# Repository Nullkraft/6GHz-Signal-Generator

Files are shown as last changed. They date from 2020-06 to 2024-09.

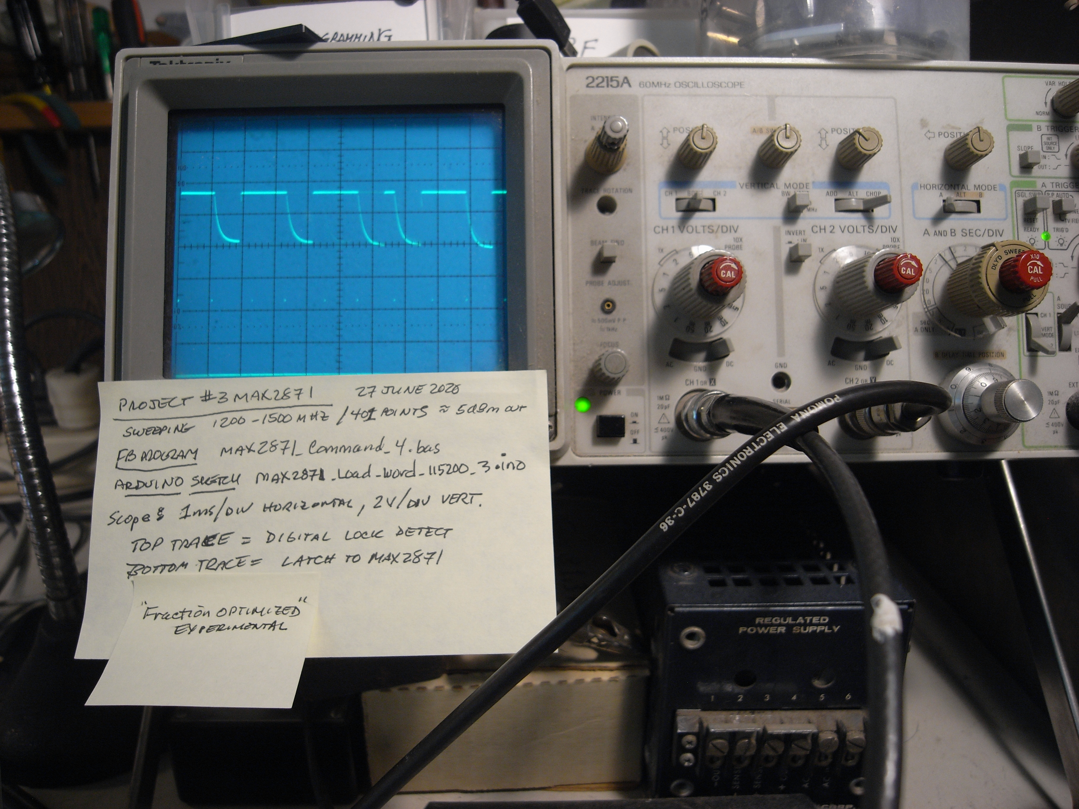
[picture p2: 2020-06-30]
Test_Data_27June2020/Timing_MAX2871_Sweep_1200-1500MHz_401pts_1ms_FracOpt.jpg

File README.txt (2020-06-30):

README for PROJECT#3 Synthesizer 6 April 2020- WN2A

A synthesizer compatible with Arduino UNO R3 Microcontroller and others.

1) Schematics: are Unembedded: wn2a-SigGen-page1B_Unembed.sch
                   Enbedded: wn2a-SigGen-page1B_Embed.sch
    
   A combination of Mark Stanley/Mike Masterson gEDA .schematics 
    
2) BOM is PROJECT#3_Synthesizer.ods

3) MAX2871 is drawn on schematic as it looks from its top-view.
    The reason is so to better visualize the optimal positions of bypass capacitors,
    for the purpose of maximizing output power especially above 3000 MHz. 

3) Design is intended to meet preliminary specifications:
   Frequency Range :23.5-6000 MHz. Step size 1KHz at min setting (TBD)
   RF Power approx -5 to +4dBm
   Harmonic Output ~ -30dBc
   Dual outputs, with divider options per MAX2871
   Powered by either by Arduino UNO R3 OR External +7 ~ +13V (Schottky Diode OR'd)
   Programmed with same interface and sketches as PROJECT#1 LO#2 ,
    (For which the MAX2871 will be LO#2 and LO#3)
   XTAL Reference 60.000 MHz for low phase noise.
   Individual AZ1117 low-noise regulators for Digital,RF and VCO
   Broadband output network.
   LOCK DET SMD LED indicator 
   Compatible with Arduino UNO R3.

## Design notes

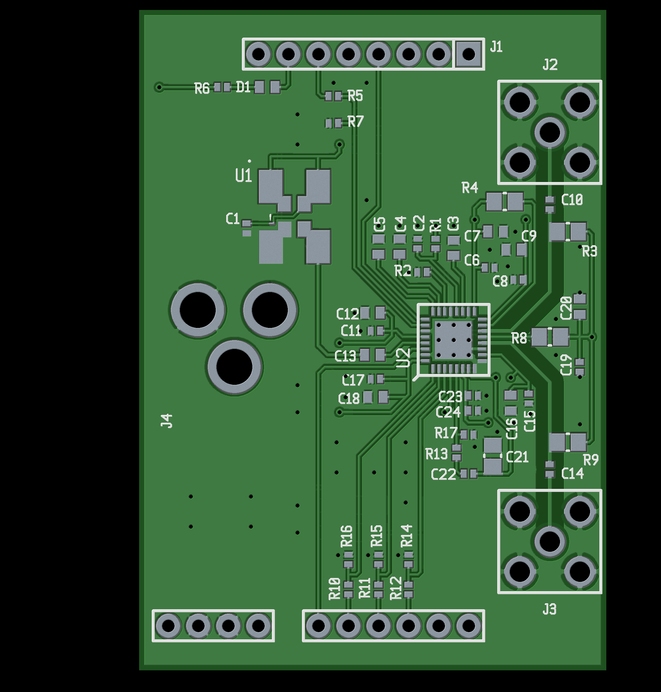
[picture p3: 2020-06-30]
Schematics/wn2a-SigGen_TOP.png

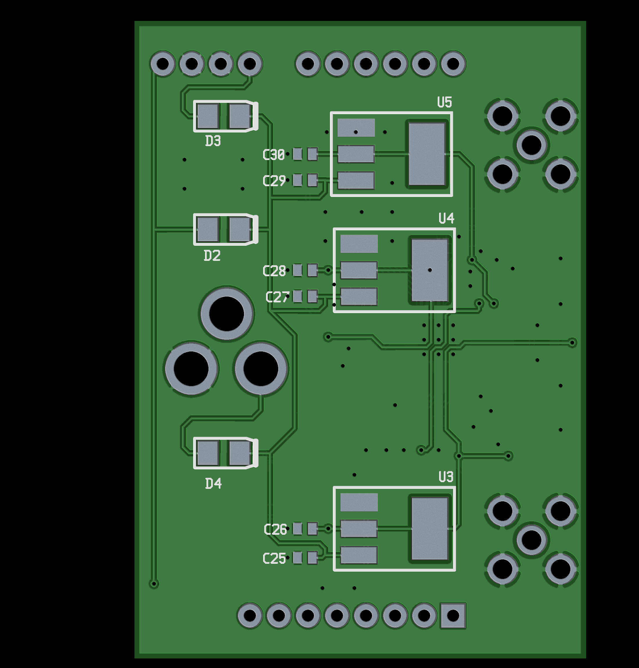
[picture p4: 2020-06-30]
Schematics/wn2a-SigGen_BOT.png

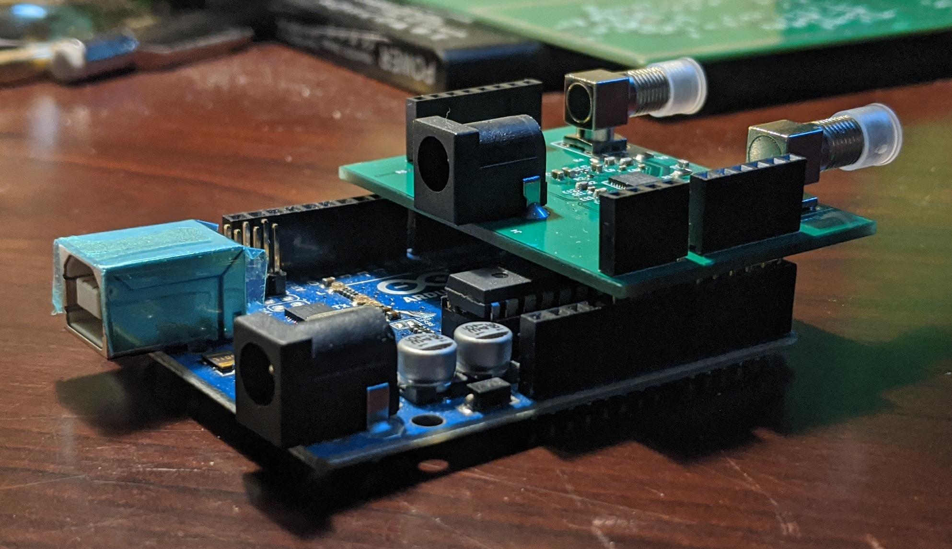
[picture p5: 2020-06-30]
Signal Generator mounting position.jpg

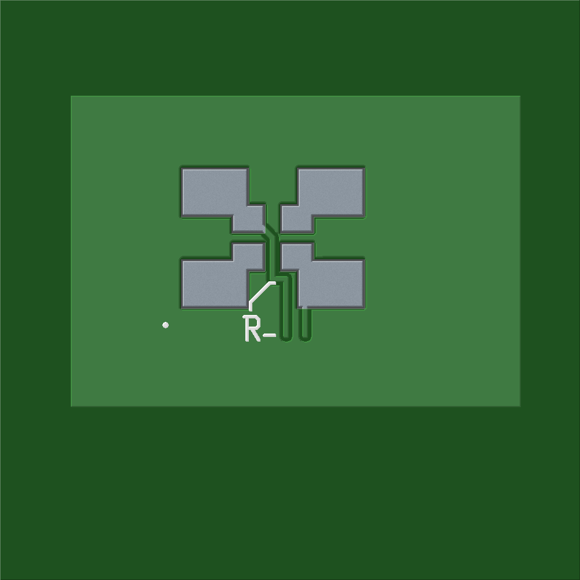
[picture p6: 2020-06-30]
ASx_Series_Oscillator.fp.png

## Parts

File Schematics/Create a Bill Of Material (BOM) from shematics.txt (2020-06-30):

Create a Bill Of Material (BOM) from shematics

Open the terminal and enter the following commands :

   - cd /Document_of_your_project
   - touch attribs : create a file that will contain the attributes you want to include in the BOM
   - touch bom.txt : Create the txt file
   - cat bom.txt : see a preview of bom.txt
   - cat attribs : see which attribs you have added
   - vi attribs : then press i to go in insertion mode
   - and write the 'options' you want to add at your build of material. (value, footprint) Refdes is automatically added.
   - when you finish presse enter, ESC and write :wq use to get out of vi attribs

   - gnetlist -g bom2 -o bom.txt wn2a-SigGen-page1.sch

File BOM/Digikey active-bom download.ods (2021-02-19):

Manufacturer Part Number | Manufacturer | Reference Designator | Digi-Key Part Number | Packaging | Part Status | Quantity | Unit Price | Extended Price | Quantity Available | Description
885012205031 | Würth Elektronik | C1 | 732-7526-1-ND | Cut Tape (CT) | Active | 10 | 0.01 | $0.10 | 71070 | CAP CER 10000PF 16V X7R 0402
885012005057 | Würth Elektronik | C10, C14 | 732-7471-1-ND | Cut Tape (CT) | Active | 10 | 0.015 | $0.15 | 32510 | CAP CER 22PF 50V C0G/NP0 0402
885012006029 | Würth Elektronik | C13 | 732-7771-1-ND | Cut Tape (CT) | Active | 1 | 0.1 | $0.10 | 7147 | CAP CER 1000PF 16V C0G/NP0 0603
GRM2195C1H123JA01D | Murata Electronics | C21 | 490-3320-1-ND | Cut Tape (CT) | Active | 1 | 0.48 | $0.48 | 29880 | CAP CER 0.012UF 50V C0G/NP0 0805
885012205037 | Würth Elektronik | C22, C24 | 732-7532-1-ND | Cut Tape (CT) | Active | 10 | 0.02 | $0.20 | 140294 | CAP CER 0.1UF 16V X7R 0402
885012206052 | Würth Elektronik | C25, C26, C27, C28, C29, C3, C30, C4, C5 | 732-7971-1-ND | Cut Tape (CT) | Active | 10 | 0.144 | $1.44 | 4469 | CAP CER 1UF 16V X7R 0603
1N5819HW-7-F | Diodes Incorporated | D2, D3, D4 | 1N5819HW-FDICT-ND | Cut Tape (CT) | Active | 3 | 0.4 | $1.20 | 493583 | DIODE SCHOTTKY 40V 1A SOD123
85 | Adafruit Industries LLC | J1 | 1528-1074-ND | Bulk | Active | 1 | 1.95 | $1.95 | 2293 | STACKING HEADER ARDUINO SHIELD
CRCW04021K00FKEDC | Vishay Dale | R10, R11, R12, R5 | 541-3961-1-ND | Cut Tape (CT) | Active | 10 | 0.032 | $0.32 | 443436 | RES SMD 1K OHM 1% 1/16W 0402
CRCW040230R1FKED | Vishay Dale | R13 | 541-30.1LCT-ND | Cut Tape (CT) | Active | 1 | 0.1 | $0.10 | 22808 | RES SMD 30.1 OHM 1% 1/16W 0402
CRCW04021K50FKEDC | Vishay Dale | R14, R15, R16, R7 | 541-4782-1-ND | Cut Tape (CT) | Active | 10 | 0.032 | $0.32 | 43118 | RES 1.5K OHM 1% 1/16W 0402

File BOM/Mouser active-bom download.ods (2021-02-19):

Mouser # | Mfr. # | Manufacturer | Customer # | Description | RoHS | Lifecycle | Order Qty. | Price (USD) | Ext.: (USD)
700-MAX2871ETJ+ | MAX2871ETJ+ | Maxim Integrated |  | Phase Locked Loops - PLL 23.5MHz to 6000MHz Fractional/IntegerN Synthesizer/VCO | RoHS Compliant |  | 1 | $11.64 | $11.64
71-CRCW04025K10FKEDC | CRCW04025K10FKEDC | Vishay |  | Thick Film Resistors - SMD 1/16watt 5.1Kohms 1% Commercial Use | RoHS Compliant By Exemption |  | 1 | $0.10 | $0.10
71-CRCW040290R9FKEDC | CRCW040290R9FKEDC | Vishay |  | Thick Film Resistors - SMD 1/16watt 90.9ohms 1% Commercial Use | RoHS Compliant By Exemption |  | 1 | $0.10 | $0.10
71-CRCW0402240RFKEDC | CRCW0402240RFKEDC | Vishay |  | Thick Film Resistors - SMD 1/16watt 240ohms 1% Commercial Use | RoHS Compliant By Exemption |  | 1 | $0.10 | $0.10
81-GCM1555C1H821JA6D | GCM1555C1H821JA16D | Murata |  | Multilayer Ceramic Capacitors MLCC - SMD/SMT 0402 820pF 50volts C0G 5% | RoHS Compliant |  | 1 | $0.10 | $0.10
81-GRM1885C1H103JA1J | GRM1885C1H103JA01J | Murata |  | Multilayer Ceramic Capacitors MLCC - SMD/SMT .01UF 50V 5% 0603 | RoHS Compliant |  | 10 | $0.148 | $1.48
815-ASE60.000MHZLCT | ASE-60.000MHZ-LC-T | ABRACON |  | Standard Clock Oscillators XTAL OSC XO 60.0000MHZ CMOS SMD | RoHS Compliant | New Product | 1 | $1.53 | $1.53
621-AZ1117EH-3.3TRG1 | AZ1117EH-3.3TRG1 | Diodes Incorporated |  | LDO Voltage Regulators LDO BJT HiCurr | RoHS Compliant |  | 10 | $0.281 | $2.81
992-CON-SOCJ-2155 | CON-SOCJ-2155 | Gravitech |  | DC Power Connectors Power Jack/Connector 2.1mm x 5.5mm | RoHS Compliant |  | 1 | $1.00 | $1.00
710-885012205020 | 885012205020 | Wurth Elektronik |  | Multilayer Ceramic Capacitors MLCC - SMD/SMT WCAP-CSGP 150pF 0402 10% 16V MLCC | RoHS Compliant |  | 10 | $0.013 | $0.13
71-CRCW080551R0FKEA | CRCW080551R0FKEA | Vishay |  | Thick Film Resistors - SMD 1/8watt 51ohms 1% | RoHS Compliant By Exemption |  | 4 | $0.10 | $0.40
571-619540-1 | 619540-1 | TE Connectivity |  | RF Connectors / Coaxial Connectors SMA RIGHT ANGLE PCB JACK | RoHS Compliant |  | 2 | $3.40 | $6.80

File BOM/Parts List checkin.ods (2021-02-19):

Source | Digi-Key Part Number | Manufacturer Part Number | Reference Designator | Description
Digikey | 732-7526-1-ND | 885012205031 | C1 | CAP CER 10000PF 16V X7R 0402
Digikey | 732-7471-1-ND | 885012005057 | C10, C14 | CAP CER 22PF 50V C0G/NP0 0402
Digikey | 732-7771-1-ND | 885012006029 | C13 | CAP CER 1000PF 16V C0G/NP0 0603
Digikey | 490-3320-1-ND | GRM2195C1H123JA01D | C21 | CAP CER 0.012UF 50V C0G/NP0 0805
Digikey | 732-7532-1-ND | 885012205037 | C22, C24 | CAP CER 0.1UF 16V X7R 0402
Digikey | 732-7971-1-ND | 885012206052 | C3, C4, C5, C25, C26, C27, C28, C29, C29 | CAP CER 1UF 16V X7R 0603
Digikey | 1N5819HW-FDICT-ND | 1N5819HW-7-F | D2, D3, D4 | DIODE SCHOTTKY 40V 1A SOD123
Digikey | 1528-1074-ND | 85 | J1 | STACKING HEADER ARDUINO SHIELD
Digikey | 541-3961-1-ND | CRCW04021K00FKEDC | R10, R11, R12, R5 | RES SMD 1K OHM 1% 1/16W 0402
Digikey | 541-30.1LCT-ND | CRCW040230R1FKED | R13 | RES SMD 30.1 OHM 1% 1/16W 0402
Digikey | 541-4782-1-ND | CRCW04021K50FKEDC | R14, R15, R16, R7 | RES 1.5K OHM 1% 1/16W 0402
Mouser | 700-MAX2871ETJ+ | MAX2871ETJ+ |  | Phase Locked Loops - PLL 23.5MHz to 6000MHz Fractional/IntegerN Synthesizer/VCO
Mouser | 71-CRCW04025K10FKEDC | CRCW04025K10FKEDC |  | Thick Film Resistors - SMD 1/16watt 5.1Kohms 1% Commercial Use
Mouser | 71-CRCW040290R9FKEDC | CRCW040290R9FKEDC |  | Thick Film Resistors - SMD 1/16watt 90.9ohms 1% Commercial Use
Mouser | 71-CRCW0402240RFKEDC | CRCW0402240RFKEDC |  | Thick Film Resistors - SMD 1/16watt 240ohms 1% Commercial Use
Mouser | 81-GCM1555C1H821JA6D | GCM1555C1H821JA16D | C2 | Multilayer Ceramic Capacitors MLCC - SMD/SMT 0402 820pF 50volts C0G 5%
Mouser | 81-GRM1885C1H103JA1J | GRM1885C1H103JA01J | C7 | Multilayer Ceramic Capacitors MLCC - SMD/SMT .01UF 50V 5% 0603
Mouser | 815-ASE60.000MHZLCT | ASE-60.000MHZ-LC-T |  | Standard Clock Oscillators XTAL OSC XO 60.0000MHZ CMOS SMD
Mouser | 621-AZ1117EH-3.3TRG1 | AZ1117EH-3.3TRG1 |  | LDO Voltage Regulators LDO BJT HiCurr
Mouser | 992-CON-SOCJ-2155 | CON-SOCJ-2155 |  | DC Power Connectors Power Jack/Connector 2.1mm x 5.5mm
Mouser | 710-885012205020 | 885012205020 |  | Multilayer Ceramic Capacitors MLCC - SMD/SMT WCAP-CSGP 150pF 0402 10% 16V MLCC
Mouser | 71-CRCW080551R0FKEA | CRCW080551R0FKEA |  | Thick Film Resistors - SMD 1/8watt 51ohms 1%
Mouser | 571-619540-1 | 619540-1 |  | RF Connectors / Coaxial Connectors SMA RIGHT ANGLE PCB JACK
 |  | 885012205019 | C6, C8, C11, C15, C17, C19, C23 | 100 pF

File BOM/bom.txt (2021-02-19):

refdes:value:man-part-num:qty
J1:unknown:1528-1074-ND:1
J4:+9VDC:CON-SOCJ-2155:1
U3,U4,U5:+3.3VDC:AZ1117EH-3.3TRG1:3
R6:150 R:CRCW0402150RFKEDC:1
D1:2 V:150060VS75000:1
R2:5.1 K:CRCW04025K10FKEDC:1
C2:820 pF:GCM1555C1H821JA16D:1
R1:240 R:CRCW0402240RFKEDC:1
C13:1 nF:885012006029:1
R14,R15,R16,R7:1.5 K:CRCW04021K50FKEDC:4
R10,R11,R12,R5:1 K:CRCW04021K00FKEDC:4
R17:90.9 R:CRCW040290R9FKEDC:1
C21:0.012 uF:GRM2195C1H123JA01D:1
R13:30.1 R:CRCW040230R1FKED:1
C22,C24:0.1 uF:885012205037:2
R3,R4,R8,R9:51 R:CRCW080551R0FKEA:4
C11,C15,C17,C19,C23,C6,C8:100 pF:885012205019:7
C12,C16,C18,C20,C7,C9:0.01 uF:GRM1885C1H103JA01J:6
C10,C14:22 pF:885012005057:2
U1:60 MHz:ASE-60.000MHZ-L-C-T:1
C1:0.01 uF:885012205031:1
C25,C26,C27,C28,C29,C3,C30,C4,C5:1.0 uF:885012206052:9
D2,D3,D4:1 A:1N5819HW-7-F:3
J2,J3:3 GHz:619540-1:2
U2:6 GHz:700-MAX2871ETJ+:1

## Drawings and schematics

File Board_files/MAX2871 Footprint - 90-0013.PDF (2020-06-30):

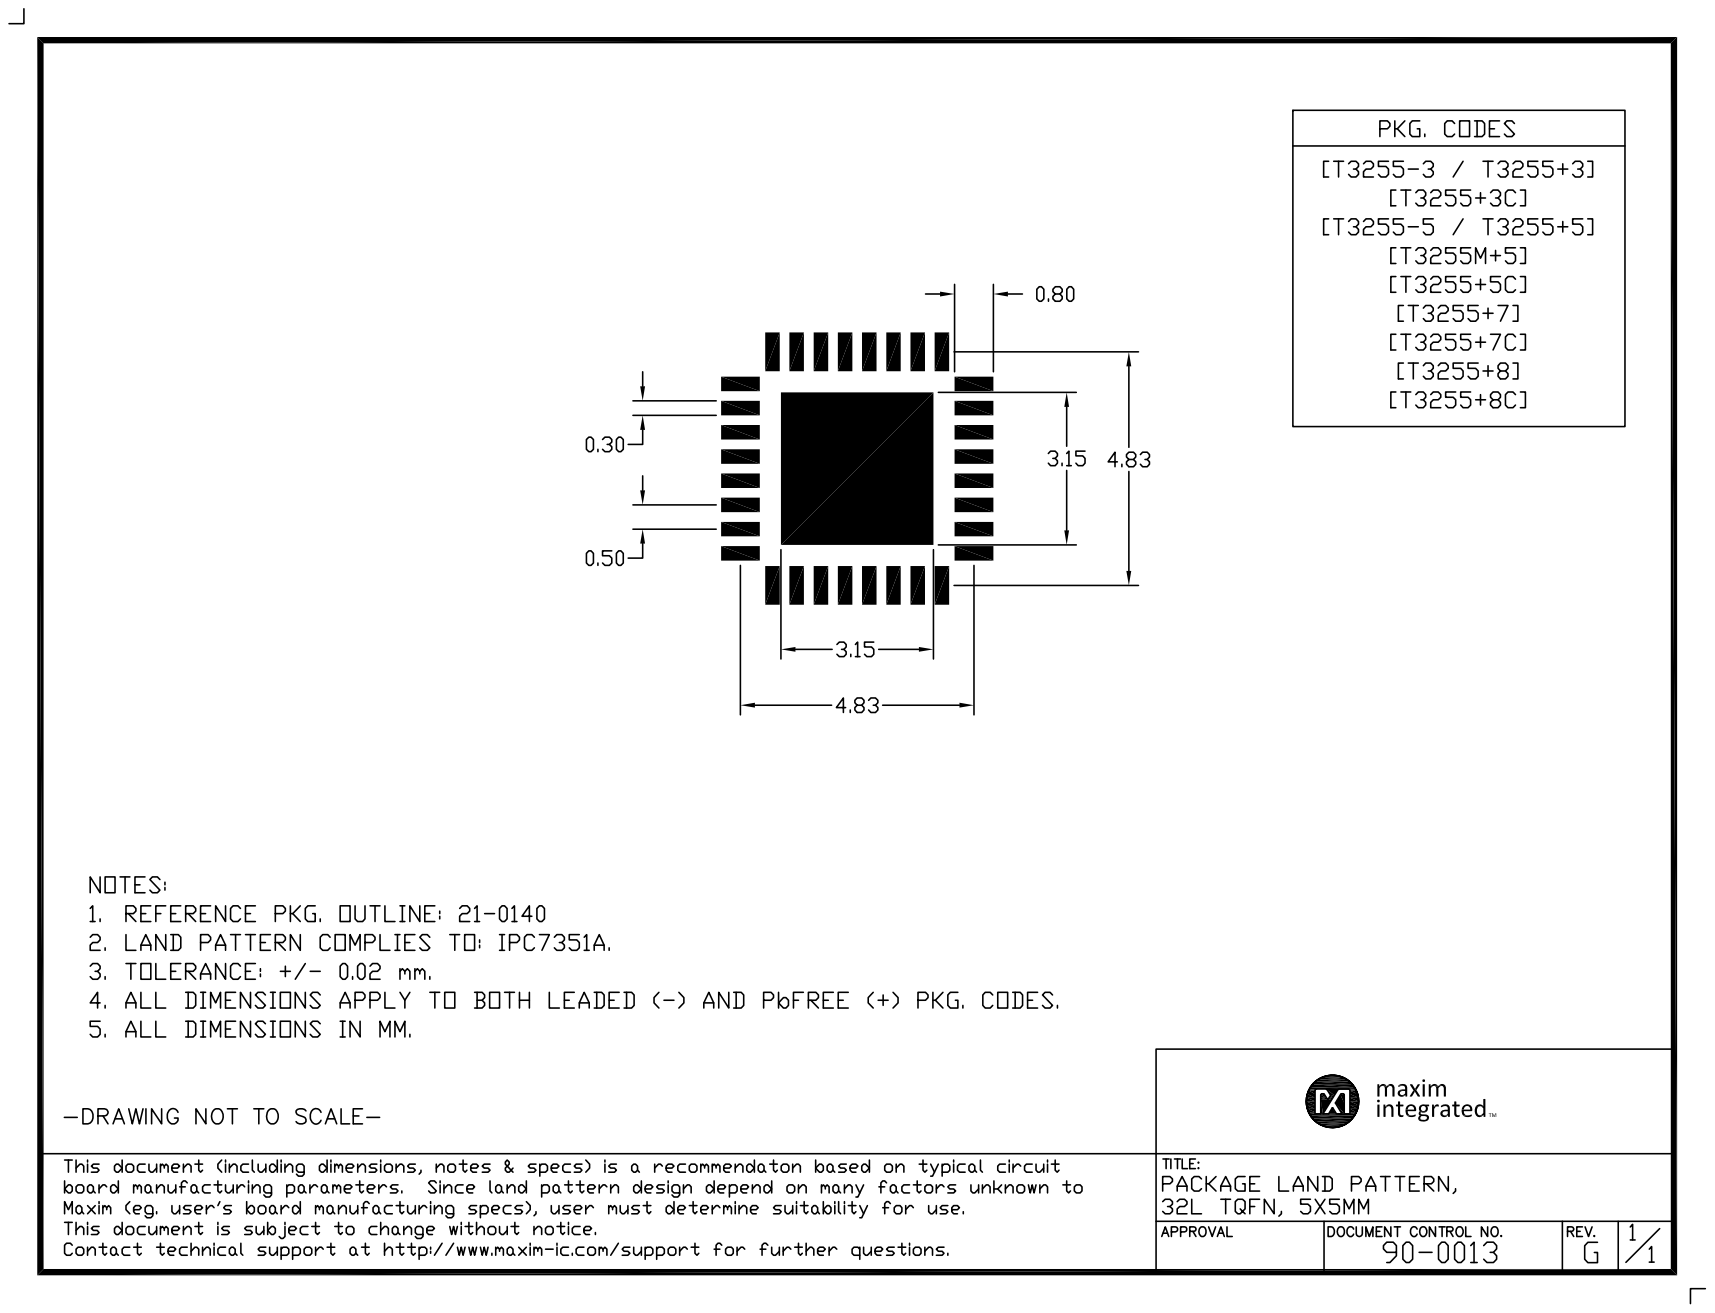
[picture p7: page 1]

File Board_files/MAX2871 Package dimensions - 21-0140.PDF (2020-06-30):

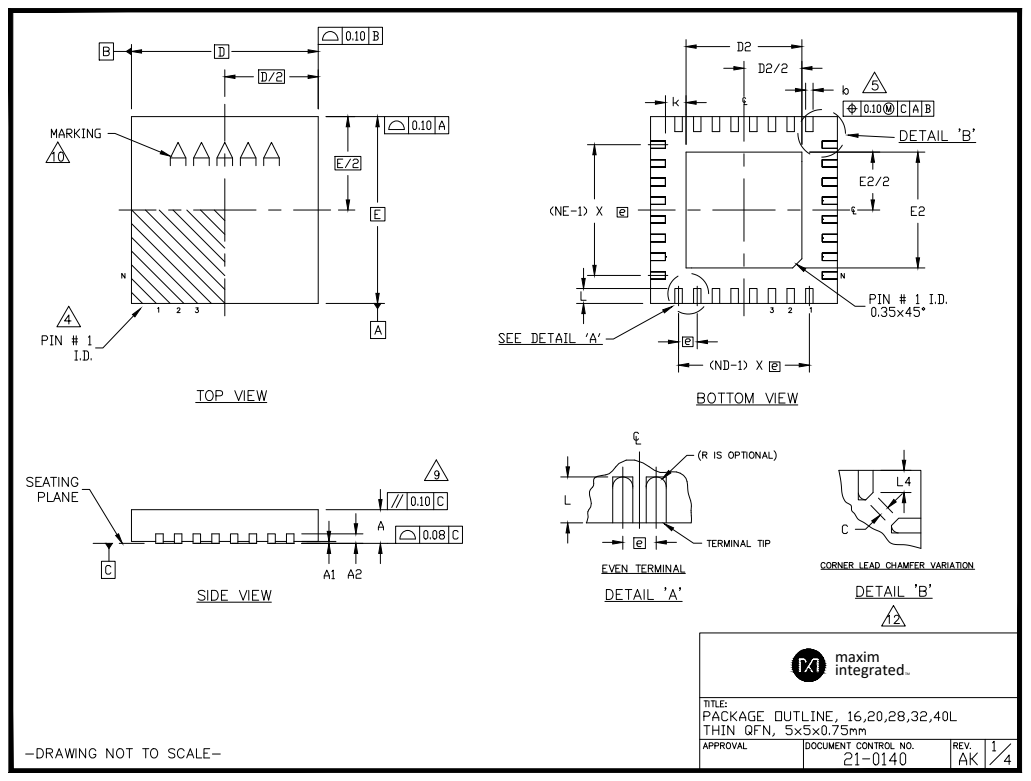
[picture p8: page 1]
maxim integratedTM

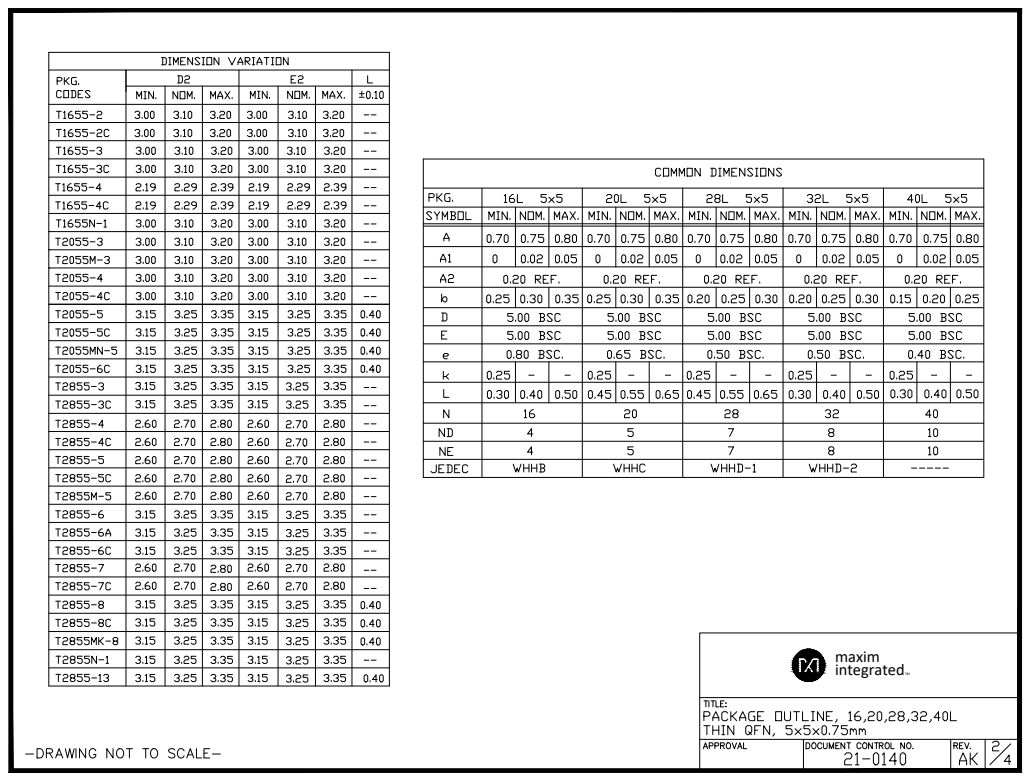
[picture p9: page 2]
maxim integratedTM

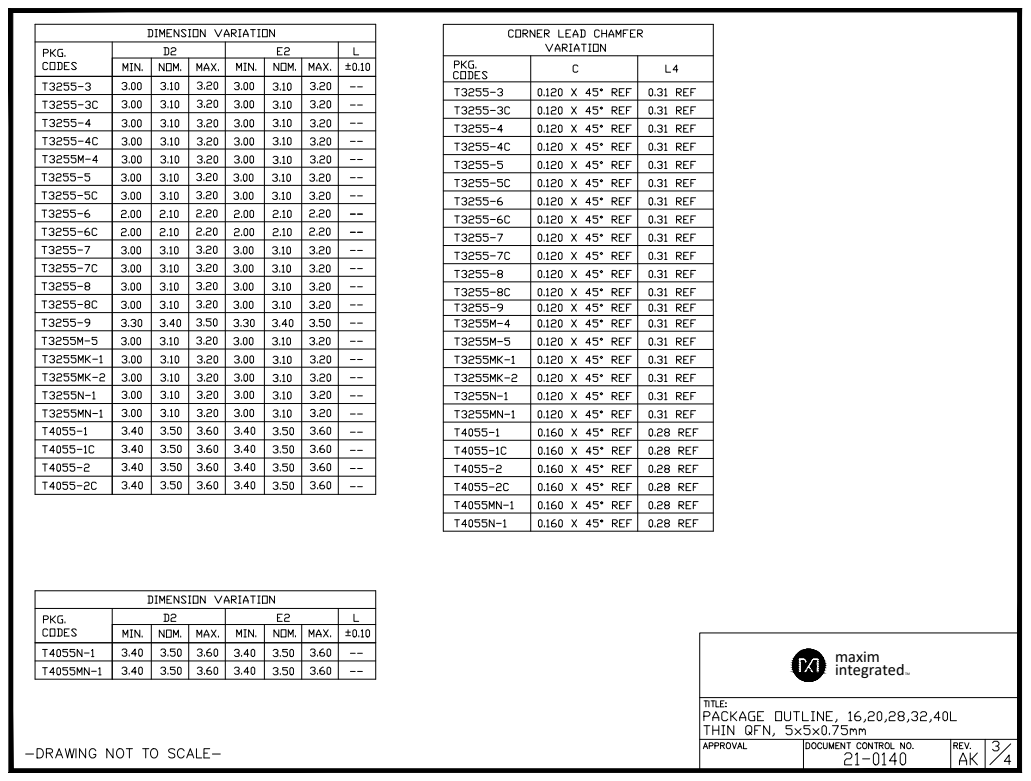
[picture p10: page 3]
maxim integratedTM

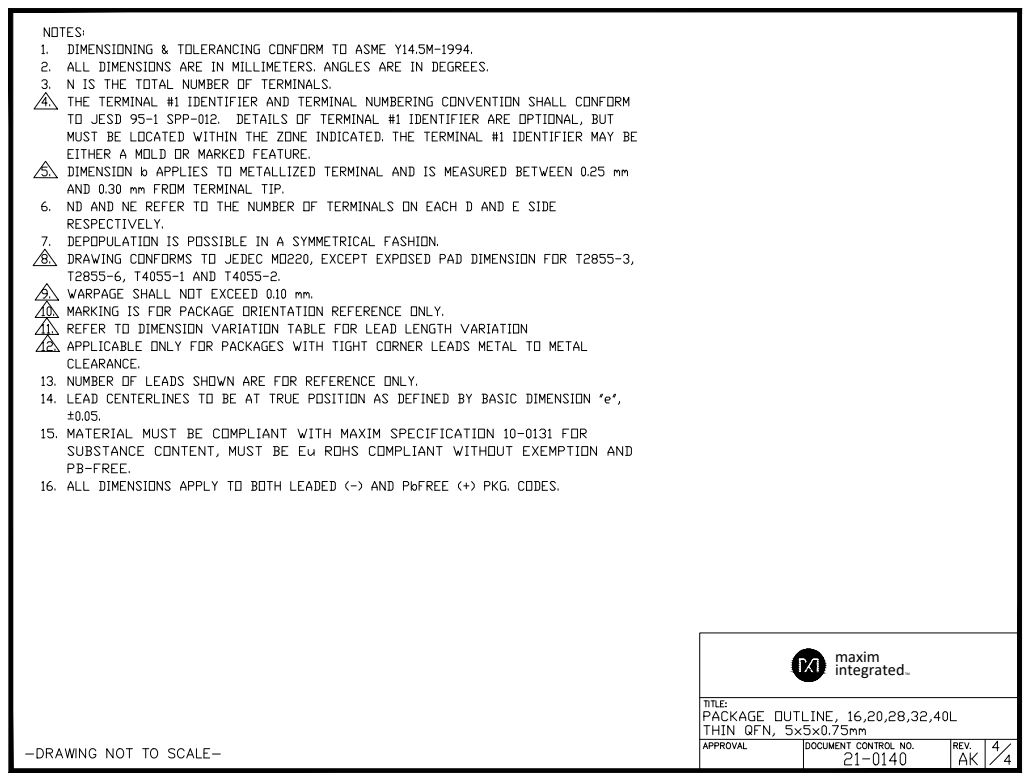
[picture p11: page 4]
maxim integratedTM

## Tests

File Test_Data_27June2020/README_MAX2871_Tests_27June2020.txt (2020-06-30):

PROJECT#3 MAX2871 Synthesizer Tests 27June2020 WN2A

1) List of files in this folder:

   A) Arduino UNO R3 Code:  MAX2871_Load_Word_115200_3.ino
                    All tests reported here done with this program.
                      
   B) FB Host Code: Used to Command a single frequency manually or sweep.
                   MAX2871_Command_4 (Linux Executable)
                   MAX2871_Command_4.bas (FB source code)
                   
   C) Screenshots of MAX2871_Command_4 running:                 
                     MAX2871_Sweep_1200-1500_401pts_1ms_DefaultFrac.png
                     MAX2871_Sweep_1200-1500_401pts_1ms_FracOpt-Beta.png

   D) Oscilloscope traces of PROJECT#3 running with  A) and B) showing PLL Lock time
                  Timing_MAX2871_Sweep_1200-1500MHz_401pts_1ms_DefaultFrac.jpg
                  Timing_MAX2871_Sweep_1200-1500MHz_401pts_1ms_FracOpt.jpg
                  
   E) MAX2871_1200-1500MHz_401pts_FractOpt.mpg. 
                  Video of the sweep mode. Sweeping 1200-1500MHz
                  401 points. This is the Fraction Optimized mode, which is experimental.
                  The Default Fraction mode is faster, due to fewer registers being updated
                  for the default fraction mode.
                  
2) Notes:
    A) Huge improvement!!! Now being able to sweep at 900 points/second (default Fraction mode)
      will permit 201 point sweeps made at>4 sweeps/sec and 401 point sweeps at >2 sweeps/sec.
      This makes the MAX2871  (LO#2) not the ADF4356 (LO#1) the preferred device to make the
      most frequent frequency changes, as the MAX2871 is faster. 
      
    B) The default fraction mode clocks in at 1.11 millisec/point (900 points/sec).
       Normally this only requires one register update from point to point, except when
       band changing. The observed spectrum looks clean as seen on my old HP8558B 
         
    C) The Fraction Optimized mode clocks in at ~2 millisec/point (500 points/sec).
       This mode normally requires two register updates from point to point,
       sometimes only one, and only when there is a band change it may require two or three.
       Note,the timing waveform shows how the cycles will vary.
       This mode should improve the Fractional-N spurs, but I cannot verify that on
       my old HP8558B.
        
    D) As before ,the little "Arduino quirk" is still there:
        In order for the Host Program to get control of the Arduino,
         this procedure was needed:
         a) Connect Arduino to Laptop via USB cable
         b) Open the Arduino IDE, check the Serial Port # (0,1,2,etc)
         c) Open the Serial Monitor. Now close the Serial Monitor and IDE.
         d) Run the FB program, either one B) or C) above.
         
         You didn't need to load any sketches or enter anything into the Serial Monitor,
         but it seemed weird that you need to open the IDE AND the Serial Monitor.
         Weird?

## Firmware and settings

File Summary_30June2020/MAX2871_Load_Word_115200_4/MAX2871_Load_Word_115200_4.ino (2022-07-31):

//************************************************************************************************
//  Name    : MAX2871_Load_Word_4.ino
//  Author  : WN2A and Mark Stanley
//  Date    : 27 June 2020
//  Version : 1.0
//  Notes   : While working on the design of a 3 GHz Spectrum Analyzer, Newark Electronics recommended
//          : the MAX2871 23.5MHz to 6000MHz Fractional/Integer-N Synthesizer/VCO as a replacement for
//          : the ADF4355. The Maxim chip was only $11 USD compared to $44 for the Analog Devices 
//          : component. But the ADF4355 had already been incorporated, and the software written, for 
//          : the current Synthesizer design. What we needed was a simple demo board that could be used
//          : to test some code for the chip. Maxim sells exactly this but we wanted to be able to 
//          : release it as open source and open hardware. You can find what you need to build it at:
//          : 
//          :     https://github.com/Nullkraft/6GHz-Signal-Generator
//          : 
//          : This sketch, MAX2871_Load_Word_4.ino, was written as a minimal hardware driver to test
//          : the operation of the MAX2871. It requires the use of a companion program 
//          : (FreeBasic: MAX2871_Command_4.bas) running on the host PC. The host PC calculates the 
//          : register values from the frequency given by the user.
//************************************************************************************************

unsigned long z;
int latchPin = A3;  // MAX2871 LE
int clockPin = A1;  // MAX2871 SCLK
int dataPin = A2;   // MAX2871 DATA
int strobe = 10;    // MAX2871 STROBE
int RF_En = 5;      // MAX2871 RF_EN
int LED = 13;       // Arduino LED
int incomingByte;

int count;

void setup() {
  Serial.begin(115200);
  Serial.println("MAX2871_Load_Word_115200_4.ino 2 July 2020");
  
  // set pins to output because they are addressed in the main loop
  pinMode(RF_En, OUTPUT);
  pinMode(latchPin, OUTPUT);
  pinMode(clockPin, OUTPUT);
  pinMode(dataPin, OUTPUT);
  pinMode(strobe, OUTPUT);
  pinMode(LED, OUTPUT);
  
  digitalWrite(RF_En, HIGH);      // Turn on the MAX2871 RF Output
  digitalWrite(LED, LOW);        // Turn on the Arduino LED
  digitalWrite(latchPin, HIGH);    // Latch must start LOW
  digitalWrite(strobe, LOW);      // Strobe must start LOW
  z = 0;
  count = 0;
}

void loop() {
  if (Serial.available()) {
    z = Serial.parseInt();
  }

  if (z > 0) {
    setFrequency();
  }
}

// Load 4 control registers of the MAX2871 for setting the frequency
void setFrequency() {
//  digitalWrite (strobe, HIGH);
//  delayMicroseconds(10);
//  digitalWrite (strobe, LOW);
  digitalWrite(latchPin, LOW);
  delayMicroseconds(10);
  shiftOut(dataPin, clockPin, MSBFIRST, z >> 24);
  shiftOut(dataPin, clockPin, MSBFIRST, z >> 16);
  shiftOut(dataPin, clockPin, MSBFIRST, z >> 8);
  shiftOut(dataPin, clockPin, MSBFIRST, z);
  delayMicroseconds(10);
  digitalWrite(latchPin, HIGH);
//  delayMicroseconds(10);
//  digitalWrite(latchPin, LOW);
}



/* Although you can download this from github I provide here just for convenience.
   MAX2871_Command_4.bas Source Code

 ******************* COPY BELOW THIS LINE *********************************


 'MAX2871_Command_4.bas for Spectrum Analyzer Freq Synthesis.
dim shared as ulong NI,x,y,z,r,Fract1,Fract2,MOD2,Reg(6,401),FpfdH,FchspH,OldReg(6),slow
 ' Reg(6,401) is Reg(x,f). 6 registers;401 max frequencies
dim shared as double Fvco,N,FracT,Num,Fchsp,Re,Fout,TimeA,TimeB
dim shared as string Ans,ComStr,Ans1,Ans2,t,delaystr,FracOpt
dim shared as string delayst,Message,Remark,Sweep
dim shared as integer div,Flag,Range,OldRange,delay,RefDiv,f
dim shared as integer MOD1,Fracc,NewMOD1,NewFracc,Mode
dim shared as single Fstart,Fstop,Freqs,Fpfd,Fref,Frf,FrfEst,FvcoEst,Initial,FracErr,Finc,Frfv(401)
Flag=0 : Remark=" Sorry Dave, I'm afraid can't do that "

sub Transmit 'This routine initializes MAX2871 at f=0
print "First we initialize the MAX2871 (twice)"
for z=0 to 1 'do the Reg 5-4-3-2-1-0 cycle twice
for y=0 to 5 : x=(5-y) 
  write #1,Reg(x,0) 'print "Hello from Transmit x= ";x;" Reg(x,0)= ";Reg(x,0);" NI=";NI;" Fracc=";Fracc;" MOD1=";MOD1
  sleep 100
  OldReg(x)=Reg(x,0)
next y
next z
Flag=1 
end sub

sub TransmitF 'For Frequency/Range or Power changes. Enter with Ref(x,f), f
 for y=0 to 5 :x=(5-y)
 if (Reg(x,f)<>OldReg(x)) then  write #1,Reg(x,f) :sleep(delay) ':Print x,f,Reg(x,f) 'Only write as required   
  OldReg(x)=Reg(x,f)
  next
end sub

sub Fraction_Opt 'Enter with FracT, leave with Fracc , MOD1
Initial=2 ': print "From Fraction_Opt Fract= ";Fract
for MOD1=4095 to 2 step -1
Fracc=int(FracT*MOD1) : FracErr=abs(FracT-(Fracc/MOD1))
if (FracErr>Initial) then goto Jumpover
NewFracc=Fracc: Initial=FracErr : NewMOD1=MOD1
Jumpover:
next
MOD1=NewMOD1 :Fracc=NewFracc
end sub

sub math   'Enter with Fpfd,Frf,f. >> Leave with Reg(x,f) 
 for x=0 to 6  'Determine divider range
  Div=(2^x)
  if (Frf*Div)>=3000 then goto Main
 next
Main:  'Divider range now known
Range=x : Fvco=Div*Frf
'Print "  Fvco= ";Fvco;" [MHz] Divider Ratio=";Div;" Frf= ";Frf;" [MHz]  Range= ";Range
N=1e6*(Fvco/(Fpfd)) : NI=int(N) : FracT=N-NI : 
if FracOpt="f" then Fraction_Opt : goto JumpMod  'Fraction_Opt : goto JumpMod
MOD1=4095 : Fracc=int(FracT*MOD1)
JumpMod: 

FvcoEst=Fpfd*(1e-6)*(NI+(Fracc/MOD1)) : FrfEst=FvcoEst/(Div) 
'print "N= ";N;" NI= ";NI;" Fracc= ";Fracc;" MOD1= ";MOD1;" Fpfd= ";Fpfd
'print "FcvoEst= ";FvcoEst;"[MHz]    FrfEst= ";FrfEst;"[MHz]   FerrEst= ";int((1e6)*(FrfEst-Frf));"[Hz]"

restore Datarow1 'Restore Data Pointer 1
for x=0 to 5 : read Reg(x,f) : next 'Initialize Reg(x,f) default decimal Values
Reg(0,f)=(NI*(2^15))+(Fracc*(2^3))
Reg(1,f)=(2^29)+(2^15)+(MOD1*(2^3))+1
Reg(4,f)=1670377980+((2^20)*Range)
end sub

Setup:
screen 18 :cls
print "MAX2871_Command_4.bas by WN2A for PROJECT#3 Signal Generator"
print "Use with Arduino MAX2871_Load_Word_115200_3.ino"
print "Supports 23.5-6000MHz. REF freq=60MHz, Experimental version with Fraction_Opt"
print "********   This version is only Beta!  ********************"
print " 1) With above sketch loaded into Arduino, start the Arduino IDE"
print " 2) Check for Serial Port#, open Serial Monitor, and set Baud=115200. Close IDE" 
print "Refer to README_MAX2871_Command.bas.txt !!":print
input "Now enter ttyACM Port 0,1 or 2 < 0 default> ";Ans1 : if Ans1="" then Ans1="0"
Ans2="115200" : Fref=60e6 : RefDiv=4 : Fpfd=Fref/RefDiv
ComStr="/dev/ttyACM"+Ans1+":"+Ans2+",N,8,1"
open com Comstr as #1

 
input "Enter delay < 2 millseconds >";delaystr : if delaystr="" then delaystr="2"
input #1 ,Message : print Message  :print
delay=val(delaystr)
input "Enable Experimental Fraction Optimization <f> or Default <Return> "; FracOpt
input "Swept <s> or Default Fixed Frequency Mode<Return>? ";Sweep :if Sweep="s" then goto Swept

Manual:
print
input "Enter Frequency [MHz] <q> to quit";Ans : if Ans="q" then goto Sleepy
Frf=val(Ans) : if (23.5>Frf) or (Frf>6000) then print Remark 
Math
if Flag=0 then Transmit else TransmitF
goto Manual

Swept:
 input "Enter Start Frequency [MHz] ";Fstart
 input "Enter Stop Frequency [MHz] ";Fstop
 input "Enter Number of Frequencies <2-401> ";Freqs
 for f=0 to (Freqs-1) :Frfv(f)=Fstart+f*(Fstop-Fstart)/(Freqs-1):Frf=Frfv(f)
 Math 'Do The Math First: f,Frfv(f)>> Reg(x,f) 
 next
 print "Math done! Press and hold <q> to quit sweeping"
WrapBack:
 for f=0 to (Freqs-1)
 if Flag=0 then Transmit else TransmitF
 next
 if inkey$<>"q" then goto Wrapback 
Sleepy:
close #1
sleep

Datarow1: 'For MAX2871 Initialization
  data  13093080,541097977,1476465218,4160782339,1674572284,2151677957 '374.596154 MHz

  
  
 ******************* COPY ABOVE THIS LINE *********************************
 
 */

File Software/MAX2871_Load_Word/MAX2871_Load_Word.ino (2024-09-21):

//************************************************
//  Name    : MAX2871_Load_Word_115200_5.ino
//  Author  : WN2A and Mark Stanley
//  Date    : 21 May 2021
//  Version : 1.0
//  Notes   : Code for using MAX2871 Synth (1 Register at a time)
//  Use with FreeBasic Program MAX2871_Command_8.bas or higher
//************************************************
#include "max2871.h"

uint32_t reg;

const uint8_t LOCK_PIN      =  3;   // MAX2871 Lock Detect
const uint8_t RF_EN_PIN     =  5;   // MAX2871 RF_EN
const uint8_t RF_EN_SWX_PIN = 12;   // Arduino RF enable signal. H=Enable
const uint8_t PLL_MUX_PIN   = A0;
const uint8_t CLOCK_PIN     = A1;   // MAX2871 SCLK
const uint8_t DATA_PIN      = A2;   // MAX2871 DATA
const uint8_t LO_SEL_PIN    = A3;   // MAX2871 LE

MAX2871_LO LO = MAX2871_LO();

int addr;


void setup() {
  // set pins to output because they are addressed in the main loop
  pinMode(LOCK_PIN, INPUT);
  pinMode(RF_EN_PIN, OUTPUT);
  pinMode(RF_EN_SWX_PIN, INPUT_PULLUP);
  pinMode(PLL_MUX_PIN, INPUT);
  pinMode(CLOCK_PIN, OUTPUT);
  pinMode(DATA_PIN, OUTPUT);
  pinMode(LO_SEL_PIN, OUTPUT);
  pinMode(LED_BUILTIN, OUTPUT);
  
  digitalWrite(RF_EN_PIN, HIGH);        // Initially turn on MAX2871 RF Output
  digitalWrite(LED_BUILTIN, LOW);       // Initially, turn off Lock Detect Indicator
  digitalWrite(LO_SEL_PIN, LOW);        // Latch must start LOW

  Serial.begin(115200);

  initialize(LO_SEL_PIN);
  // initialize_LO(LO_SEL_PIN, do_init);
  // initialize_LO(LO_SEL_PIN, dont_init);
  Serial.println("MAX2871_Load_Word_115200_5.ino 21 May 2021");
}

/* Example register programming values for a 60 MHz reference clock
 MHz   R[5]      R[4]    R[3]    R[2]       R[1]     R[0]
 30   4194309,1677623548,7971,2550161218,1073807377,2097152
 40   4194309,1677623548,7971,2550161218,1073807385,2785288
 60   4194309,1676574972,7971,2550161218,1073808361,2097152
 90   4194309,1676574972,7971,2550161218,1073808361,3145728
*/
void loop() {
  if (Serial.available()) {
    reg = Serial.parseInt();
  }

  if (reg > 0) {
    addr = reg & 0x00000007;    // First 3 bits are the chip Register address
    if (LO.Curr.Reg[addr] != reg) {
      LO.Curr.Reg[addr] = reg;
      spiWriteLO(LO.Curr.Reg[addr], LO_SEL_PIN);
      Serial.print("Reg[");
      Serial.print(addr);
      Serial.println("] updated");
    }
    Status();
  }
  reg = 0;
}


/* IAW Manufacturer's PDF document "MAX2871 - 23.5MHz to 6000MHz Fractional/Integer-N Synthesizer/VCO"
   pg. 13 4-Wire Serial Interface during initialization there should be a 20mS delay after programming
   register 5.                                                  Document Version: 19-7106; Rev 4; 6/20
*/
void initialize(uint8_t csPin) {
  spiWriteLO(LO.Curr.Reg[5], csPin);    // First we program LO Register 5
  delay(20);  // wait 20 mSec for MAX2871 internal capacitors to charge
  spiWriteLO(LO.Curr.Reg[4], csPin); // Program remaining registers
  spiWriteLO(LO.Curr.Reg[3], csPin); // Program remaining registers
  spiWriteLO(LO.Curr.Reg[2], csPin); // Program remaining registers
  spiWriteLO(LO.Curr.Reg[1], csPin); // Program remaining registers
  spiWriteLO(LO.Curr.Reg[0], csPin); // Program remaining registers
  delay(1);                               // Short delay before reading Register 6
  MuxTest();                              // Check if LO is locked by reading the Mux pin
  spiWriteLO(LO.Curr.Reg[6], csPin);  // Tri-stating the mux output disables LO2 lock detect
}


// Program a single register of the selected LO by sending and latching 4 bytes
void spiWriteLO(uint32_t reg, uint8_t selectPin) {
  digitalWrite(LO_SEL_PIN, LOW);
  shiftOut(DATA_PIN, CLOCK_PIN, MSBFIRST, reg >> 24);
  shiftOut(DATA_PIN, CLOCK_PIN, MSBFIRST, reg >> 16);
  shiftOut(DATA_PIN, CLOCK_PIN, MSBFIRST, reg >> 8);
  shiftOut(DATA_PIN, CLOCK_PIN, MSBFIRST, reg);
  delayMicroseconds(10);
  digitalWrite(LO_SEL_PIN, HIGH);
  delayMicroseconds(10);
  digitalWrite(LO_SEL_PIN, LOW);
}



//Test LOCK_PIN.RF_EN_SWX_PIN, drive GRN light
void Status() {
  int stat = 0;

  if (digitalRead(RF_EN_SWX_PIN) == HIGH ) {
    stat = 1;
    digitalWrite(RF_EN_PIN, HIGH);
  } else {
    digitalWrite(RF_EN_PIN, LOW);
  }

  if (digitalRead(LOCK_PIN) == HIGH ) {
    stat = stat + 2;
  }
  if (stat == 3 ) {
    digitalWrite(LED_BUILTIN, HIGH);
  } else {
    digitalWrite(LED_BUILTIN, LOW);
  }
  // stat=0 unlock,RF off; 1= unlock,RF on; 2=lock, RF off; 3=lock,RF on
}


// When the mux pin is configured for Digital Lock Detect output
// we can read the status of the pin from here.
void MuxTest() {
  char* LOStatus = " LO UNLOCKED";

  if (digitalRead(PLL_MUX_PIN)) {
    LOStatus = " LO LOCKED";
  }
  
  Serial.println(LOStatus);
}

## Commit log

2020-06-30 Initialized existing 6GHz Signal Generator project
    [Digikey active-bom download.ods, Mouser active-bom download.ods, Power supply limits.ods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]
2021-02-19 Finalize project
    [Digikey active-bom download.ods, Mouser active-bom download.ods, Parts List checkin.ods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]
2022-07-31 Catch up with current work
    Lost all projects in a drive failure and when restored from backups there were a lot of things that needed to be caught up. Think of this as more of an initial commit.
    [wn2a-SigGen-page1.sch]
2022-07-31 Fix missing Arduino Header footprint
    [wn2a-SigGen-page1.sch]
2024-09-21 Commit custom PCB footprints to this repo
2024-09-21 Commit custom schematic symbols to this repo
2024-09-21 gitignore PCB .save files
2024-09-21 Add signal name for +5 Vout
    [wn2a-SigGen-page1.sch]
